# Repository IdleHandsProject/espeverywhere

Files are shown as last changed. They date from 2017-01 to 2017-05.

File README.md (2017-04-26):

# ESPEverywhere
ESP8266 Special Make/100 Kickstarter Edition

ESP Everywhere

Check out why this board exists here:
https://www.youtube.com/watch?v=67Kh_ikb-ds

Thanks to the Backers of the #Make100(And the others as well!):  
Rolandas Launikonis  
Erlend Schei  
Andrew Chalkley  
Anthony Castaneda  
APSoft  
Arjuna Chatrathi  
Ashutosh Dubey  
Avinash Magdum  
BLUNT  
Bobby C C Wong  
Brian Linaburg  
Brian Willis  
Bruce Shipman  
Burrish  
DeltaLima  
Cardel Quaiatto  
Chaz Stone  
Chris Arnesen  
Christian Wilhelm  
Craig Hissett  
Dan Rothstein  
Danny Yo  
David Choi  
Death by snu snu  
Doug  
Fabio Cevasco  
Francisco Ribeiro  
Francesco Farruggia  
Grégoire Gustin  
Hank Terwilliger  
Hanya-zou  
Jeff Herndon  
Joe Key  
Jon Peer  
Jordan Moore  
Chris Cunningham  
Lewis Harrison-Wood  
Marco Hegenberg  
Mark Lee  
Mark Selph  
Milan Maletic  
Michael Gwincinski  
Mike Paulson  
Tim Lawson  
Michael Miranda  
Nick Piper  
Nick Goodall  
Nuno Santos  
PHK  
Wayne San  
Rob Arao  
Russell Calbert  
S. Lee Fowler  
Shabaz Mohammad  
SmilingRex Reyes  
Stephan Thomas  
Steve Farrage  
Will Ryan  
Yitzi Baum  

The ESP Everywhere was made to take part in the Kickstarter Make/100 Campaign
You can get 1 of 100 boards assembled by me. Or you can Make your own.
Kickstarter is here:
https://www.kickstarter.com/projects/idlehandsdev/esp-everywhere-kickstarter-special-make-100

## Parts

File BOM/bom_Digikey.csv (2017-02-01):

ref | value | footprint | Digikey Part No. | Mouser Part No. | Quantity
C1 C7 C8 | 0.1uF | project_footprints:C_0402_Hand | 490-6328-1-ND |  | 3
L1 | FB | Resistors_SMD:R_0805_HandSoldering | 240-2390-1-ND |  | 1
C4 C5 | 47pF | project_footprints:C_0402_Hand | 490-6241-1-ND |  | 2
D2 | BAT20J | project_footprints:sod323 | 497-3381-1-ND |  | 1
C2 | 1uF | project_footprints:C_0402_Hand | 490-1320-1-ND |  | 1
D3 | RXLED | idlehands_footprints:Led_0603 | 160-1448-1-ND |  | 1
U1 | AP2112K-3.3V | TO_SOT_Packages_SMD:SOT-23-5 | AP2112K-3.3TRG1DICT-ND |  | 1
D4 D5 | TXLED | idlehands_footprints:Led_0603 | 160-1446-1-ND |  | 2
U3 | FT230XS | Housings_SSOP:SSOP-16_3.9x4.9mm_Pitch0.635mm | 768-1135-1-ND |  | 1
R9 R10 | 27R | idlehands_footprints:R_0402_Hand | 311-27JRCT-ND |  | 2
F1 | 500mA | idlehands_footprints:c_1206 | 507-1802-1-ND |  | 1
P1 | USB_OTG |  | 609-4618-1-ND |  | 1
D1 | PWR | idlehands_footprints:Led_0603 | 160-1447-1-ND |  | 1
R1 R2 R5 | 10K | idlehands_footprints:R_0402_Hand | 311-10KJRCT-ND |  | 3
R4 R3 R6 R7 R8 R11 R12 R13 | 1K | idlehands_footprints:R_0402_Hand | 311-1.0KJRCT-ND |  | 8
C3 | 2.2uF | project_footprints:C_0402_Hand | 490-10451-1-ND |  | 1
C6 C9 | 10uF | project_footprints:C_0402_Hand | 490-1718-1-ND |  | 2
P3 | Conn | CONN_01x08 | 455-1808-1-ND |  | 1

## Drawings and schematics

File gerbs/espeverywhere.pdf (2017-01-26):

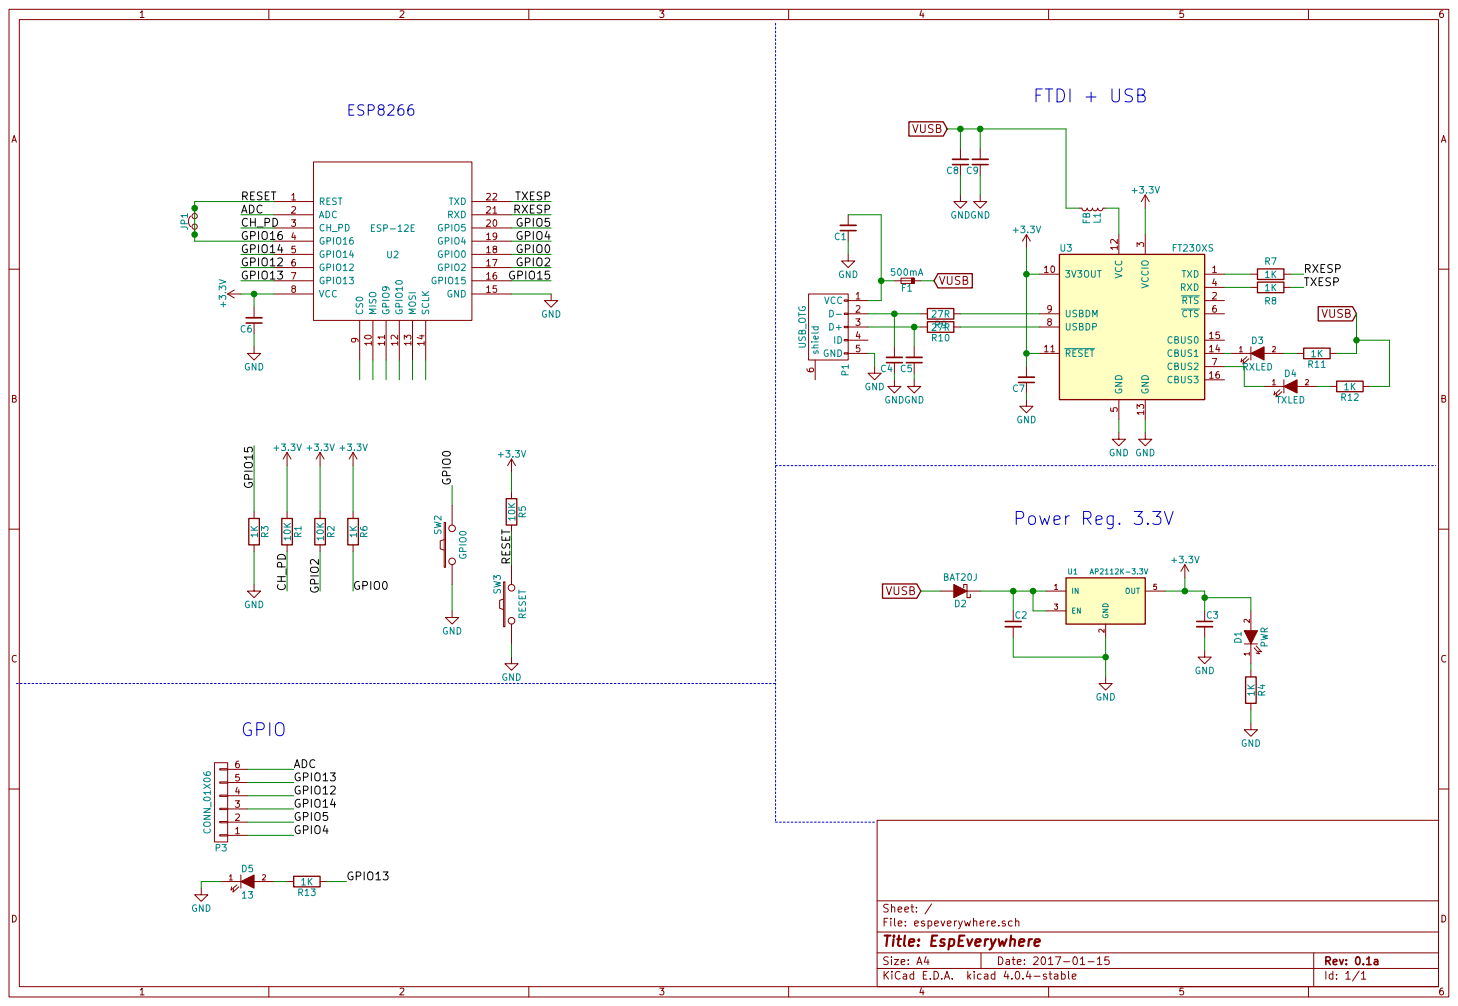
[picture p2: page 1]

File: espeverywhere.sch Sheet: /
Id: 1/1 Title: EspEverywhere

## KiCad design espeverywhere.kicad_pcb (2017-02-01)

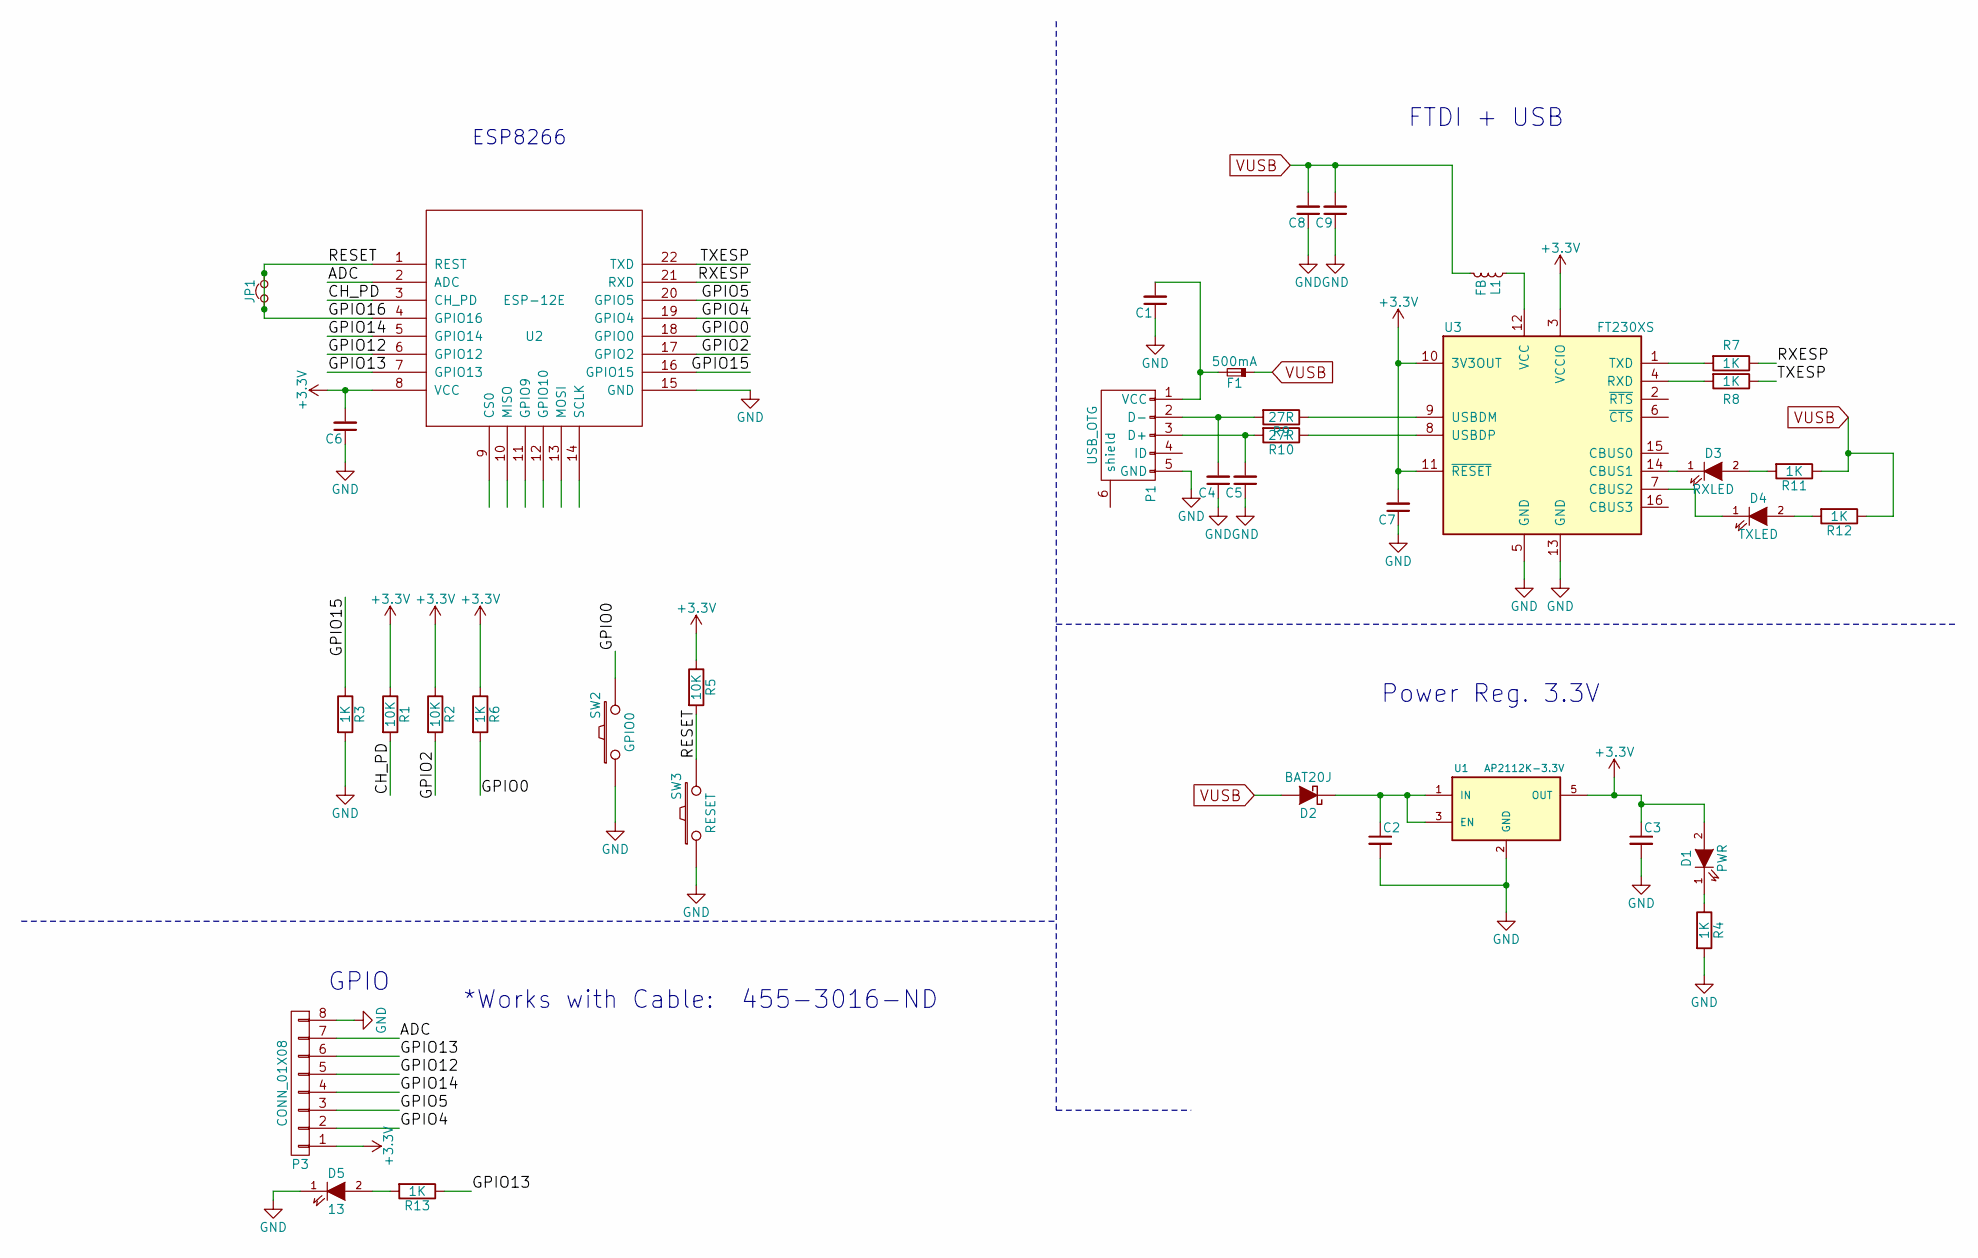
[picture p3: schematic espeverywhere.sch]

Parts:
C1, C7, C8: 0.1uF; C_0402_Hand; Digikey Part No. 490-6328-1-ND
C2: 1uF; C_0402_Hand; Digikey Part No. 490-1320-1-ND
C3: 2.2uF; C_0402_Hand; Digikey Part No. 490-10451-1-ND
C4, C5: 47pF; C_0402_Hand; Digikey Part No. 490-6241-1-ND
C6, C9: 10uF; C_0805; Digikey Part No. 490-1718-1-ND
D1: PWR; Led_0603; Digikey Part No. 160-1447-1-ND
D2: BAT20J; sod323; Digikey Part No. 497-3381-1-ND
D3: RXLED; Led_0603; Digikey Part No. 160-1448-1-ND
D4: TXLED; Led_0603; Digikey Part No. 160-1446-1-ND
D5: 13; Led_0603; Digikey Part No. 160-1446-1-ND
F1: 500mA; c_1206; Digikey Part No. 507-1802-1-ND
JP1: Jumper_NC_Small; SOLDER-JUMPER_1-WAY-CLOSED
L1: FB; R_0805_HandSoldering; Digikey Part No. 240-2390-1-ND
P1: USB_OTG; Digikey Part No. 609-4618-1-ND
P3: CONN_01X08; Connectors_JST_SM08B-SRSS-TB; Digikey Part No. 455-1808-1-ND
R1, R2, R5: 10K; R_0402_Hand; Digikey Part No. 311-10KJRCT-ND
R3, R4, R6, R7, R8, R11, R12, R13: 1K; R_0402_Hand; Digikey Part No. 311-1.0KJRCT-ND
R9, R10: 27R; R_0402_Hand; Digikey Part No. 311-27JRCT-ND
SW2: GPIO0; PTS-LFS; Digikey Part No. CKN9112CT-ND
SW3: RESET; PTS-LFS; Digikey Part No. CKN9112CT-ND
U1: AP2112K-3.3V; SOT-23-5; Digikey Part No. AP2112K-3.3TRG1DICT-ND
U2: ESP-12E
U3: FT230XS; SSOP-16_3.9x4.9mm_Pitch0.635mm; Digikey Part No. 768-1135-1-ND

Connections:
+3V3: C3.1, C6.2, C7.2, D1.2 (A), P3.1, R1.1, R2.1, R5.1, R6.1, U1.5 (OUT), U2.8 (VCC), U3.3 (VCCIO), U3.10 (3V3OUT), U3.11 (~RESET)
/ADC: P3.7, U2.2 (ADC)
/CH_PD: R1.2, U2.3 (CH_PD)
/GPIO0: R6.2, SW2.2, U2.18 (GPIO0)
/GPIO2: R2.2, U2.17 (GPIO2)
/GPIO4: P3.2, U2.19 (GPIO4)
/GPIO5: P3.3, U2.20 (GPIO5)
/GPIO12: P3.5, U2.6 (GPIO12)
/GPIO13: P3.6, R13.1, U2.7 (GPIO13)
/GPIO14: P3.4, U2.5 (GPIO14)
/GPIO15: R3.1, U2.16 (GPIO15)
/GPIO16: JP1.1, JP1.2, R5.2, SW3.2, U2.1 (REST), U2.4 (GPIO16)
/RXESP: R7.1, U2.21 (RXD)
/TXESP: R8.1, U2.22 (TXD)
GND: C1.1, C2.2, C3.2, C4.1, C5.1, C6.1, C7.1, C8.1, C9.1, D5.1 (K), P1.5 (GND), P3.8, R3.2, R4.2, SW2.1, SW3.1, U1.2 (GND), U2.15 (GND), U3.5 (GND), U3.13 (GND)
unnamed: C1.2, F1.2, P1.1 (VCC)
unnamed: C2.1, D2.1 (K), U1.1 (IN), U1.3 (EN)
unnamed: C4.2, P1.2 (D-), R9.2
unnamed: C5.2, P1.3 (D+), R10.2
unnamed: D1.1 (K), R4.1
unnamed: D3.1 (K), U3.14 (CBUS1)
unnamed: D3.2 (A), R11.2
unnamed: D4.1 (K), U3.7 (CBUS2)
unnamed: D4.2 (A), R12.2
unnamed: D5.2 (A), R13.2
unnamed: L1.1, U3.12 (VCC)
unnamed: R7.2, U3.1 (TXD)
unnamed: R8.2, U3.4 (RXD)
unnamed: R9.1, U3.9 (USBDM)
unnamed: R10.1, U3.8 (USBDP)
VUSB: C8.2, C9.2, D2.2 (A), F1.1, L1.2, R11.1, R12.1

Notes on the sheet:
ESP8266
FTDI + USB
GPIO
Power Reg. 3.3V
*Works with Cable: 455-3016-ND

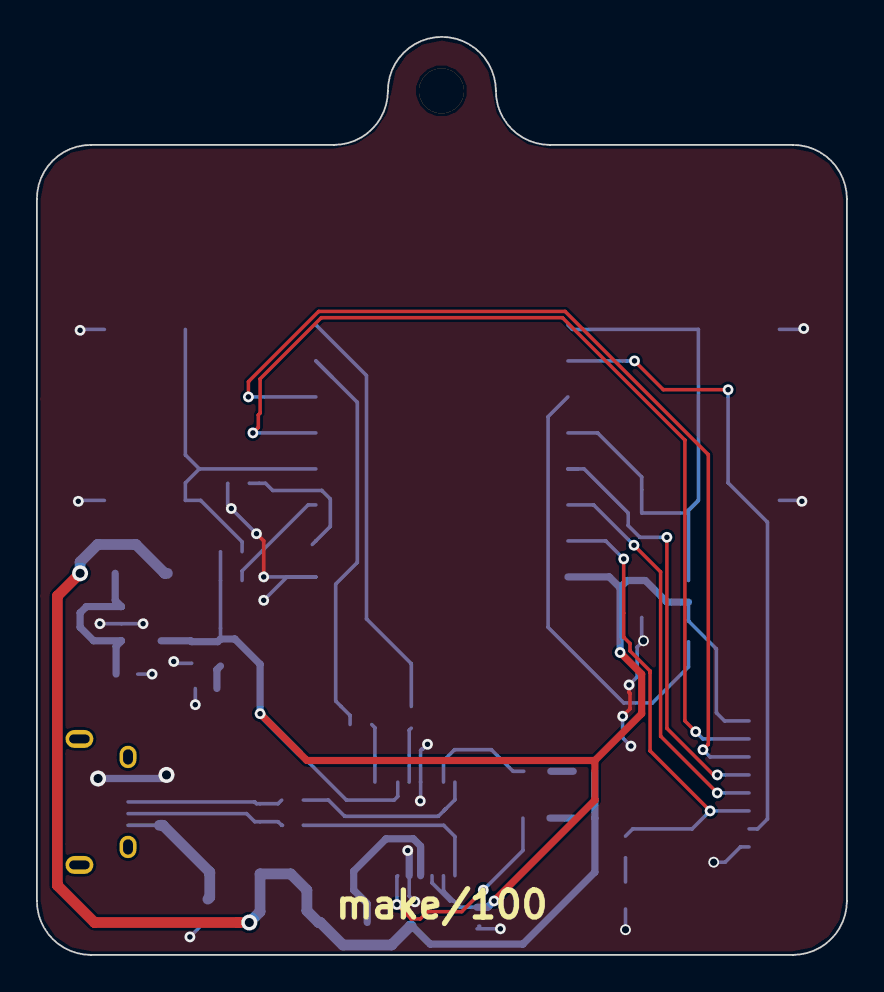
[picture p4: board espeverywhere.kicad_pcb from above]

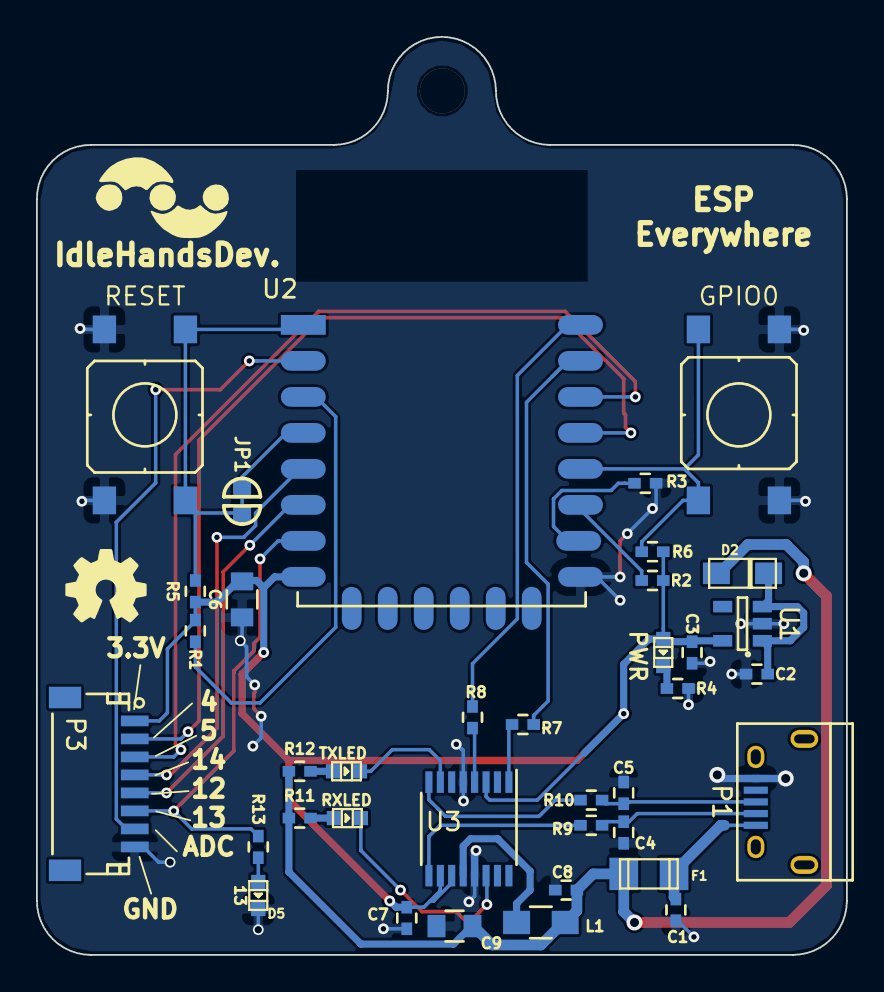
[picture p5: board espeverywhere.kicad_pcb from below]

Board: 2 copper layers, 45.0 x 51.0 mm, 37 parts (37 on the bottom side), 31 nets.

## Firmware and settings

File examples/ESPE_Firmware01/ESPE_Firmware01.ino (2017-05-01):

/*****************
 * ESP Everywhere Default Firmware
 * Created by Sean Hodgins - Idle Hands Dev.
 * It will blink the LED pin 3 times then load wifi manager, thats all!
 * Check out the Build video at http://youtube.com/seanhodginsfilms - don't forget to subscribe!
 * *****
 * */

#include <ESP8266WiFi.h>          //https://github.com/esp8266/Arduino
#include <DNSServer.h>
#include <ESP8266WebServer.h>
#include <WiFiManager.h>         //https://github.com/tzapu/WiFiManager
#include <WiFiClient.h>

#define LED 13

void setup() {
  // put your setup code here, to run once:
   pinMode(LED, OUTPUT);
   Serial.begin(115200);
  
  for (int x = 0; x<3; x++){
  digitalWrite(LED,HIGH);
  Serial.println("LED");
  delay(500);
  digitalWrite(LED, LOW);
  delay(500);

  }
  
  Serial.println("I'm Working!");


  WiFiManager wifiManager;
  //reset saved settings
  //wifiManager.resetSettings();

  //set custom ip for portal
  //wifiManager.setAPConfig(IPAddress(10,0,1,1), IPAddress(10,0,1,1), IPAddress(255,255,255,0));

  //fetches ssid and pass from eeprom and tries to connect
  //if it does not connect it starts an access point with the specified name
  //here  "AutoConnectAP"
  //and goes into a blocking loop awaiting configuration
  wifiManager.autoConnect("ESP Everywhere");
  //or use this for auto generated name ESP + ChipID
  //wifiManager.autoConnect();

  Serial.println("Connected");

  
}

void loop() {
  // put your main code here, to run repeatedly:
  Serial.println("Don't forget to check for your name on the youtube video!");
  Serial.println("Http://youtube.com/seanhodginsfilms");
  delay(5000);
}

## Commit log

2017-01-30 Updated BOM and Gerbs
    [bom_Digikey.csv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]
2017-02-01 Changed JST-SH-6 to 8 Pin
    [espeverywhere.kicad_pcb, espeverywhere.sch]
2017-02-01 Breakout Board added
    [_saved_espeverywhere_breakout.sch, bom_Digikey.csv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]
